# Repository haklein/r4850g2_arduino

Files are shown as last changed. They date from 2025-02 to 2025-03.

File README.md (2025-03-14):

# Huawai R4850G2 rectifier canbus control

  ## Based on:

   https://www.beyondlogic.org/review-huawei-r4850g2-power-supply-53-5vdc-3kw/
   https://github.com/craigpeacock/Huawei_R4850G2_CAN

  ## IMPORTANT

   - adjust CAN.setClockFrequency() to match the crystal on the MCP2515 Board
   - put a termination jumper on J1, didn't work without for me (AZDelivery MCP2515 board)
   - be careful with any Serial.print statements in the onReceive handler. This will lead to lost CAN frames.
   - no regular status request CAN frames are being sent while the menu is active, so the rectifier will
     fall back to offline values at some point (menu will hence timeout after 10s by default)

  ## Requirements 
   
   - this has been tested with an Arduino Mega 2560 and a Nano
   - libraries used:
      * Adafruit can library (forked from sandeepmistry/arduino-CAN):
        https://github.com/adafruit/arduino-CAN
      * ArduinoMenu (for Sketch `R4850G2_Menu.ino`, not required for `R4850G2_V2.ino`)
      * SSD1306Ascii (for Sketch `R4850G2_Menu.ino`, not required for `R4850G2_V2.ino`)
      * ClickEncoder (for Sketch `R4850G2_Menu.ino`, not required for `R4850G2_V2.ino`)

  ## Usage

Pressing the rotary button opens the menu. Voltage and current can be set with the rotary encoder. The "Apply" menu item sets the power supply to the chosen values. Using the "Persist" menu item (scroll down below "Apply") will permanently store the settings in the power supply. Those will then be the default startup values. The power supply will also fall back to those values when the CAN commuication is interrupted.
    
  ## PICTURES:









  ## PINOUT

  @Roturbo has provided a nice pinout for a nano: 

  316427349-3ad49603-3def-4ec2-9e40-f8289db90cfa

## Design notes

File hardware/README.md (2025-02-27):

# Hardware

This directory contains the schematics PDF and the Gerber zip.

PCB 2d view front
PCB 3d view front

The footprint for the SSD1306 has reversed SDA/SCL. The latest gerber fixes this (I2C pins cannot be changed on the pro mini).

## BOM

- Arduino Nano Pro
- EC11 rotary encoder (e.g. PEC11R-4215F-S0024)
- SSD1306 display
- MCP2515 CAN bus module (will be mounted flipped so boards with already soldered pins can be used)
- 2x 100nF 0805 for rotary debounce
- 2x 3,5mm screw terminal (optional, one can be salvaged from the CAN bus module)
- Female headers 2.54mm (optional when the break out boards are soldered directly to the PCB)

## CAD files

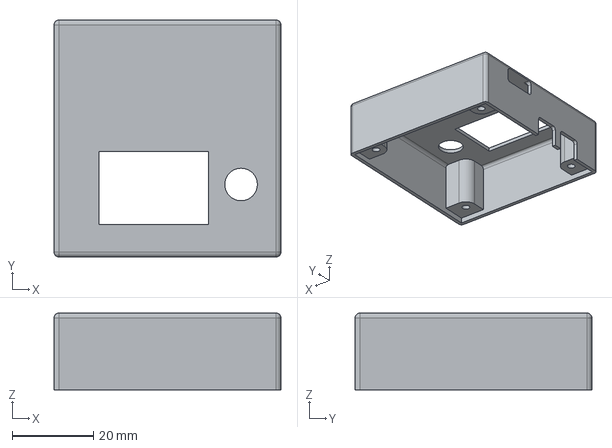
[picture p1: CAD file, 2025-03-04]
hardware/rg4850ctrl-BodyPocket001.step
55.8 x 58.2 x 18.9 mm

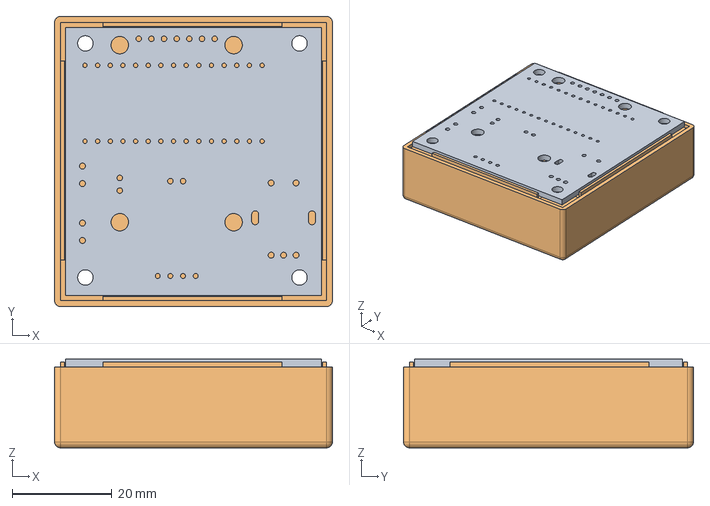
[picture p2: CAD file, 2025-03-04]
hardware/rg4850ctrl.FCStd
55.8 x 58.2 x 17.8 mm
BackupProjects_hari_1326_personal_0_20250303_PCB
Bottom

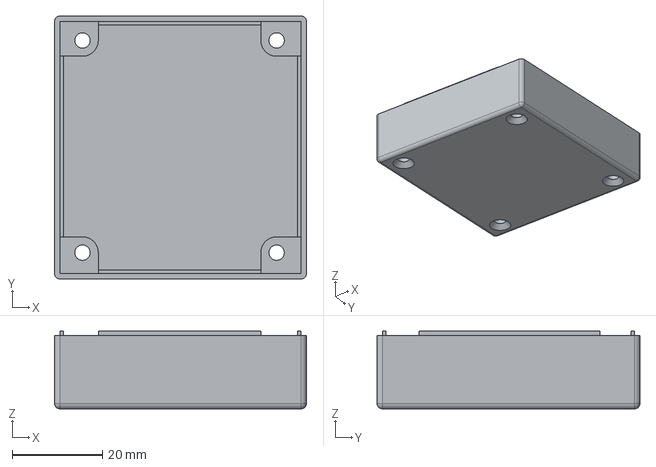
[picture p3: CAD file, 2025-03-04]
hardware/rg4850ctrl-BottomPad005.step
55.8 x 58.2 x 17.2 mm

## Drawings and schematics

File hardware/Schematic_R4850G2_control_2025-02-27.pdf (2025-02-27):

Arduino | CAN bus module | SSD 1306 Display

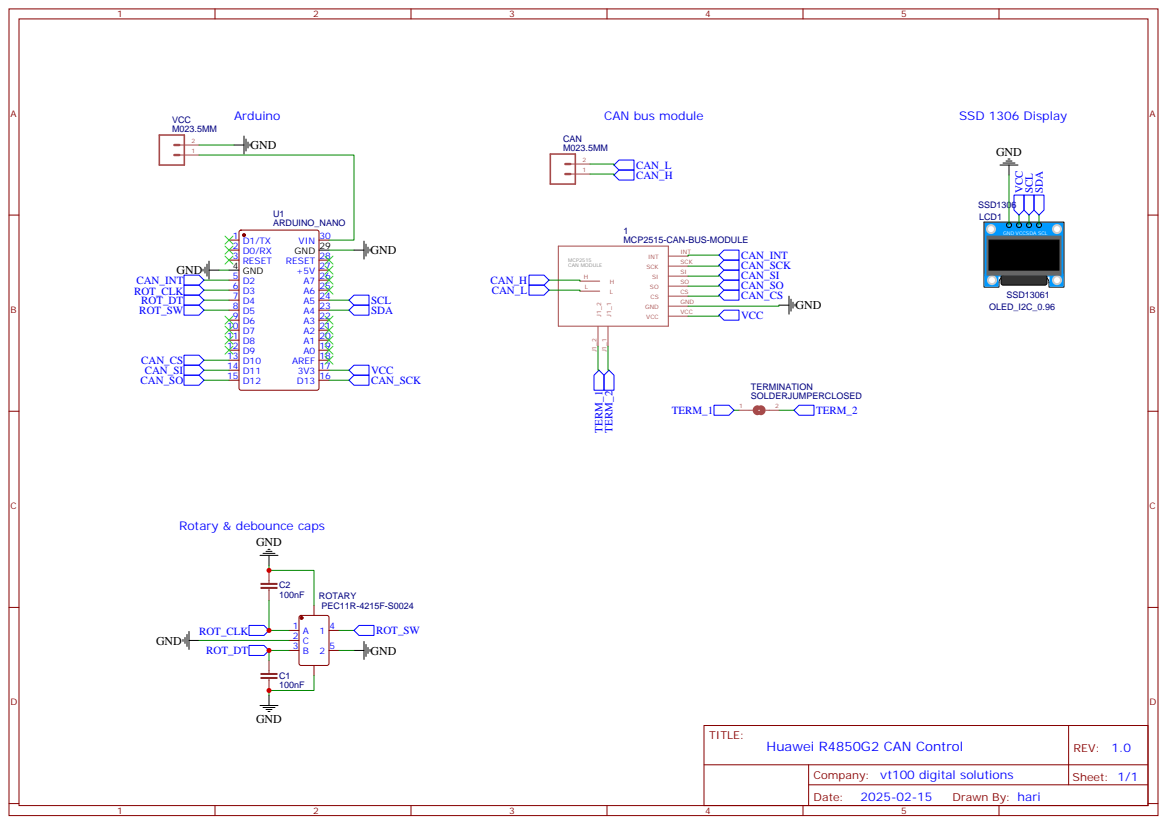
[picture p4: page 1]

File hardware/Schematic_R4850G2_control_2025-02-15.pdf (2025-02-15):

Arduino | CAN bus module | SSD 1306 Display

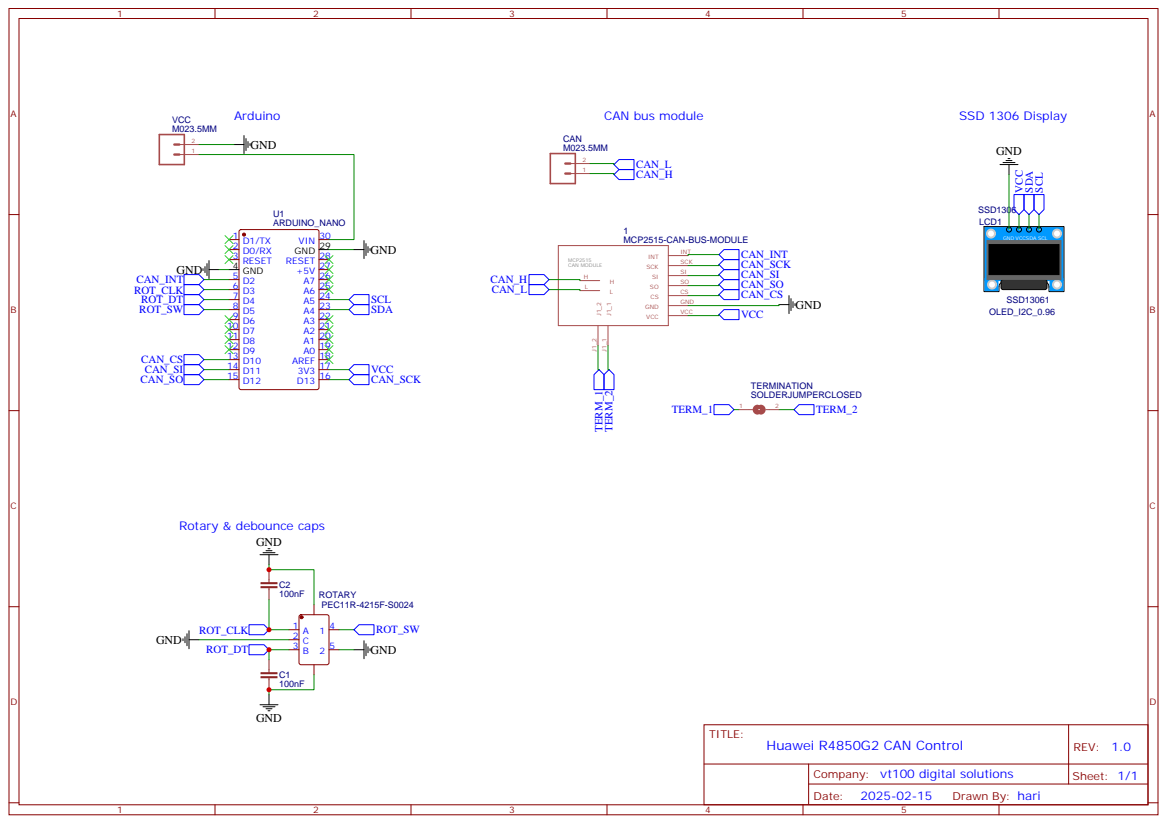
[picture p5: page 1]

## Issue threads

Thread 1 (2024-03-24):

Oled

Roturbo, 2024-03-24:
Hello,

i try to build this to adjust my r4850 power supply but no joy, display not working.

i have use 4 and 5 for oled SDA and SCL, i have 2 types of oled, the 0.96 and the 1.2" and they are working
because i try with other sketch.

Example, with sketch SH106-128-64_i2c, ssd1306_128x32_i2c, DisplayRotationWire,  Wire128x64SH1106 the oled works.

Can you please post the schematics for correct connection for oled and can-bus board,  also the type of Oled to use ?

Tanks in advance

.

haklein, 2024-03-24:
Hi, you do use the `R4850G2_Menu.ino` Sketch, right? Line 42 defines the i2c address of the Oled module. I'm using the 0.96" 1306 one. br Hari

Roturbo, 2024-03-25:
Hi,

the problem was the missing can module, the software hangs if there is no communication with the
can module and the display stays black,, i have look for the pin out and connect it, and it is working normal.

How about give the option to use the Oled 1.3" SH1106 ?

I leave here the connections,, if you want put it on first page to help others in future.

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

Regards

haklein, 2024-03-26:
Thanks a lot, I've added the pinout to the readme! I do not have a SH1106 to test, but feel free to submit a PR.

Roturbo, 2024-03-26:
Hi, ,

i will open a PR for the SH1106.

The picture is "private-user-images.",, i think you need to save it on you PC and upload it again for everyone to see it on the readme page.

regards.

haklein, 2024-03-26:
just did that, thanks!

Roturbo, 2024-03-28:
Hello,

Sorry i don´t have knowledge to make this type of changes and open a PR, my programming skills are very low.

The 1.3" oled is working, one or two vertical lines missing on the left but it is ok,  if you want and have the chance
to change the code i can try it and report here.

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

It´s working,, tank you for this.

Regards.

Closed 2024-05-19.

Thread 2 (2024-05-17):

menu version don't work per default

dl1bz, 2024-05-17:
The menu version don't work here , I found two problems:
1.
Reason: you forget to initialize the I2C bus:
add
```
Wire.begin();
Wire.setClock(400000L);
```
in the setup() function before you initialize the OLED, otherwise the 328 will be stopping/hang up.

2.
The second problem: runs not at an Arduino Nano per default.
Reason: compiled code to big for this CPU. You need to reduce code like some serial outputs. Use here the Arduino IDE 2.x with actual versions of all needed libs and using Ardunio Nano V3 from AZ Delivery and the 1,3" OLED display, which need a short patch too:
`oled.begin(&SH1106_128x64, SCREEN_ADDRESS);`

I2C address is in this case 0x3C (most 1.3" OLEDs are using 0x3D) for my display I use.

You can add a short scan routine for checking the I2C bus (helpful for find out the correct address for the used OLED):
```
//-----------------------------------------------------------------------------------------------------
// scan I2C bus for connected devices
void scanI2C() {
  byte error, address;
  int nDevices = 0;

  // Wire.begin();  // if not done before start I2C bus
  Serial.println(F("Scanning for I2C devices ..."));
  for(address = 0x01; address < 0x7f; address++){
    Wire.beginTransmission(address);
    error = Wire.endTransmission();
    if (error == 0){
      Serial.print(F("I2C device found at address 0x"));Serial.println(address,HEX);
      nDevices++;
    } else if(error != 2){
      Serial.print(F("Error "));Serial.print(error);Serial.print(F(" at address 0x"));Serial.println(address,HEX);
    }
  }
  if (nDevices == 0){
    Serial.println(F("No I2C devices found"));
  }
  delay(3000);
}
//-----------------------------------------------------------------------------------------------------
```

After this fixes your program works :)

haklein, 2024-05-19:
Looking at the examples from the SSD1306Ascii library this didn't seem to be mandatory. Also it did work for me on two different boards (nano and mega2560) and also for other users. Still good to know that this might be required in some situations, so thanks a lot for your comment! I didn't use the Version 2 IDE a lot as I do find PIO & vscode much more convenient. 73

Closed 2024-05-19.

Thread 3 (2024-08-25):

menu.h error

buddhafragt, 2024-08-25:
Hello, while compiling I always get a error:
.....R4850G2_Menu.ino:130:1: error: 'result' does not name a type
 result persist(eventMask e) {

Do you have a idea, whats wrong? I try different Arduino IDE versions and Arduinomenu versions, but still the same.

buddhafragt, 2024-08-29:
can not find the reason....
maybe the clickencoder library is wrong, which one you use?

haklein, 2024-09-02:
> can not find the reason.... maybe the clickencoder library is wrong, which one you use?

I think the one from 0xpit, need to check. You could try his `platformio.ini` (move the ino sketch to a directory named `src`):
```
[platformio]

[env:nanoatmega328]
platform = atmelavr
board = nanoatmega328

framework=arduino
lib_deps=
	neu-rah/ArduinoMenu library@^4.21.4
	greiman/SSD1306Ascii@^1.3.5
	0xpit/ClickEncoder
	sandeepmistry/CAN@^0.3.1
	paulstoffregen/TimerOne@^1.1.1
```

buddhafragt, 2024-09-05:
Thanks, I was trying to compile with the ArduinoIDE, this is not working.
With PlatformIO the code compiles.
Suggestion:
With my board I need to change in the .ini file the board to:
board = nanoatmega328new

Closed 2024-09-05.

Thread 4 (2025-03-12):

Request: Set default power voltage

myhobby2, 2025-03-12:
Removed initial request because with scanning the written Arduino code (I can't program), I saw that it should be possible to set the default start values.

Can you provide a short manual how to use the controller to set/change values so it is clear to me. Currently working based on assumptions ;-)

haklein, 2025-03-13:
Hello @myhobby2

you can "persist" the setting via the menu. This is the action right below the "apply". Persisted values will be the default start ones, and the power supply also reverts to them when the CAN communication is lost.

br Hari

myhobby2, 2025-03-14:
Thanks for your confirmation. Initially I did not see this option in the menu for whatever reason. I think you created a wonderful solution. As a new user to your work, I'm working with a lot of assumptions in the menu and that is why I asked for a few words on using the menu and dail/push button.. (I think it is still the icing on the cake ;-) )

haklein, 2025-03-14:
I've added usage notes to the readme.

Closed 2025-03-14.

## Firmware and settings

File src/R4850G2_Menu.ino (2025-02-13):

/*
   Huawai R4850G2 rectifier canbus control


   Based on:

   https://www.beyondlogic.org/review-huawei-r4850g2-power-supply-53-5vdc-3kw/
   https://github.com/craigpeacock/Huawei_R4850G2_CAN

   Improvements from dl1bz

   IMPORTANT:

   - adjust CAN.setClockFrequency() to match the crystal on the MCP2515 Board
   - put a termination jumper on J1, didn't work without for me
   - be careful with any Serial.print in the onReceive handler. This will lead to lost CAN frames.
   - this has been tested with an Arduino Mega 2560 and Nano
   - libraries used:
        Adafruit can library (forked from sandeepmistry/arduino-CAN):
        https://github.com/adafruit/arduino-CAN
        ArduinoMenu
        SSD1306Ascii
        ClickEncoder

   Mega 2560 SPI pins:

   2 - int
   10 - CS
   50 - SO
   51 - SI
   52 - SCK
*/

#define menuFont X11fixed7x14
#define fontW 7  // 7
#define fontH 15   // 15

#define statusFont Adafruit5x7

#define SCREEN_WIDTH 128 // OLED display width, in pixels
#define SCREEN_HEIGHT 64 // OLED display height, in pixels

#define OLED_RESET     4 // Reset pin # (or -1 if sharing Arduino reset pin)
#define SCREEN_ADDRESS 0x3c ///< See datasheet for Address; 0x3D for 128x64, 0x3C for 128x32

#define ROTARY_PIN_CLK 3
#define ROTARY_PIN_DT 4
#define ROTARY_PIN_SW 5

#define VOLT_LIMIT_LOW 41.5
#define VOLT_LIMIT_HIGH 58.5
#define AMP_LIMIT_LOW 0.0
#define AMP_LIMIT_HIGH 60.0

#define VOLT_DEFAULT 55.2 
#define AMP_DEFAULT 1.0

#define MENU_TIMEOUT 10  // sketch doesn't send CAN frames while in menu, so timeout early to prevent
                         // rectifier from defaulting to offline values
                         
#define MAX_DEPTH 1 // menu depth

#include <CAN.h>

#include <SPI.h>
#include <Wire.h>

#include <SSD1306Ascii.h>
#include <SSD1306AsciiWire.h>

#include <TimerOne.h>

#include <ClickEncoder.h>

#include <menu.h>
#include <menuIO/SSD1306AsciiOut.h>
#include <menuIO/clickEncoderIn.h>
#include <menuIO/keyIn.h>
#include <menuIO/chainStream.h>

#define DEBUG 1

#define MAX_CURRENT_MULTIPLIER    20

#define R48xx_DATA_INPUT_POWER    0x70
#define R48xx_DATA_INPUT_FREQ   0x71
#define R48xx_DATA_INPUT_CURRENT  0x72
#define R48xx_DATA_OUTPUT_POWER   0x73
#define R48xx_DATA_EFFICIENCY   0x74
#define R48xx_DATA_OUTPUT_VOLTAGE 0x75
#define R48xx_DATA_OUTPUT_CURRENT_MAX 0x76
#define R48xx_DATA_INPUT_VOLTAGE  0x78
#define R48xx_DATA_OUTPUT_TEMPERATURE 0x7F
#define R48xx_DATA_INPUT_TEMPERATURE  0x80
#define R48xx_DATA_OUTPUT_CURRENT 0x81
#define R48xx_DATA_OUTPUT_CURRENT1  0x82

struct RectifierParameters
{
  float input_voltage;
  float input_frequency;
  float input_current;
  float input_power;
  float input_temp;
  float efficiency;
  float output_voltage;
  float output_current;
  float max_output_current;
  float output_power;
  float output_temp;
  float amp_hour;
};

using namespace Menu;

SSD1306AsciiWire oled;

ClickEncoder clickEncoder(ROTARY_PIN_CLK, ROTARY_PIN_DT, ROTARY_PIN_SW, 4); // last parameter: steps per notch
ClickEncoderStream encStream(clickEncoder, 1);

struct RectifierParameters rp;

unsigned long g_Time1000 = 0;

bool doPrint = false;

float volts = VOLT_DEFAULT;
float amps = AMP_DEFAULT;

result persist(eventMask e) {
  Serial.println(F("persist executed")); Serial.flush();
  Serial.println(volts);
  Serial.println(amps);
  r4850_set_voltage(volts, true);
  delay(250);
  r4850_set_current(amps, true);
  delay(250);
  return proceed;
}

result apply(eventMask e) {
  Serial.println(F("apply executed")); Serial.flush();
  Serial.println(volts);
  Serial.println(amps);
  r4850_set_voltage(volts, false);
  delay(250);
  r4850_set_current(amps, false);
  delay(250);
  return quit;
}

result doAlert(eventMask e, prompt &item);

MENU_INPUTS(in, &encStream);

MENU(mainMenu, "R4850 Settings", Menu::doNothing, Menu::noEvent, Menu::wrapStyle
     , FIELD(volts, "Volts", "V", VOLT_LIMIT_LOW, VOLT_LIMIT_HIGH, 1, 0.1, doNothing, noEvent, wrapStyle)
     , FIELD(amps, "Amps", "A", AMP_LIMIT_LOW, AMP_LIMIT_HIGH, 1, 0.1, doNothing, noEvent, wrapStyle)
     , OP(">Apply", apply, enterEvent)
     , OP(">Persist", persist, enterEvent)
     , EXIT("<Back")
    );

const panel panels[] MEMMODE = {{0, 0, 128 / fontW, 64 / fontH}};
navNode* nodes[sizeof(panels) / sizeof(panel)]; //navNodes to store navigation status
panelsList pList(panels, nodes, 1); //a list of panels and nodes
idx_t tops[MAX_DEPTH] = {0}; //store cursor positions for each level
SSD1306AsciiOut outOLED(&oled, tops, pList, 8, 1+((fontH - 1) >> 3) ); //oled output device menu driver
menuOut* constMEM outputs[] MEMMODE = {&outOLED}; //list of output devices
outputsList out(outputs, 1); //outputs list

NAVROOT(nav, mainMenu, MAX_DEPTH, in, out);

int r4850_ack(uint8_t *frame)
{
  bool error = frame[0] & 0x20;
  uint32_t value = __builtin_bswap32(*(uint32_t *)&frame[4]);

  switch (frame[1]) {
    case 0x00:
      Serial.print(F("Setting on-line voltage: "));
      break;
    case 0x01:
      Serial.print(F("Setting off-line voltage: "));
      break;
    case 0x02:
      Serial.print(F("Setting OVP: "));
      break;
    case 0x03:
      Serial.print(F("Setting on-line current: "));
      break;
    case 0x04:
      Serial.print(F("Setting off-line current: "));
      break;
    default:
      Serial.print(F("Setting unknown parameter: "));
      break;
  }
  Serial.println(error ? F("ERROR") : F("SUCCESS"));
}

int r4850_data(uint8_t *frame, struct RectifierParameters *rp)
{
  uint32_t value = __builtin_bswap32(*(uint32_t *)&frame[4]);

  switch (frame[1]) {
    case R48xx_DATA_INPUT_POWER:
      rp->input_power = value / 1024.0;
      break;

    case R48xx_DATA_INPUT_FREQ:
      rp->input_frequency = value / 1024.0;
      break;

    case R48xx_DATA_INPUT_CURRENT:
      rp->input_current = value / 1024.0;
      break;

    case R48xx_DATA_OUTPUT_POWER:
      rp->output_power = value / 1024.0;
      break;

    case R48xx_DATA_EFFICIENCY:
      rp->efficiency = value / 1024.0;
      break;

    case R48xx_DATA_OUTPUT_VOLTAGE:
      rp->output_voltage = value / 1024.0;
      break;

    case R48xx_DATA_OUTPUT_CURRENT_MAX:
      rp->max_output_current = value / MAX_CURRENT_MULTIPLIER;
      break;

    case R48xx_DATA_INPUT_VOLTAGE:
      rp->input_voltage = value / 1024.0;
      break;

    case R48xx_DATA_OUTPUT_TEMPERATURE:
      rp->output_temp = value / 1024.0;
      break;

    case R48xx_DATA_INPUT_TEMPERATURE:
      rp->input_temp = value / 1024.0;
      break;

    case R48xx_DATA_OUTPUT_CURRENT1:
      // Serial.println("R48xx_DATA_OUTPUT_CURRENT1");
      //printf("Output Current(1) %.02fA\r\n", value / 1024.0);
      //rp->output_current = value / 1024.0;
      break;

    case R48xx_DATA_OUTPUT_CURRENT:
      rp->output_current = value / 1024.0;

      /* This is normally the last parameter received. Print */
      doPrint = true;
      break;

    default:
      //printf("Unknown parameter 0x%02X, 0x%04X\r\n",frame[1], value);
      break;

  }
}


void onCANReceive(int packetSize)
{
  if (!CAN.packetExtended())
    return;
  if (CAN.packetRtr())
    return;

  uint32_t msgid = CAN.packetId();
  uint8_t data[packetSize];

  CAN.readBytes(data, sizeof(data));

  switch (msgid & 0x1FFFFFFF) {

    case 0x1081407F:
      // Serial.print("Data frame: ");
      r4850_data((uint8_t *)&data, &rp);
      // Serial.println();
      break;
    case 0x1081407E:
      /* Acknowledgment */
      // Serial.println("Ack frame");
      break;
    case 0x1081D27F:
      // Serial.println("Description");
      // r4850_description((uint8_t *)&frame.data);
      break;
    case 0x1081807E:
      // Serial.println("Ack frame");
      r4850_ack((uint8_t *)&data);
      break;
    case 0x1001117E:
      // Serial.println("Amp hour frame");
      break;
    case 0x100011FE:
      // Serial.println("Normally  00 02 00 00 00 00 00 00 ");
      break;
    case 0x108111FE:
      // Serial.println("Normally 00 03 00 00 00 0s 00 00, s=1 when output enabled ");
      break;
    case 0x108081FE:
      // Serial.println("Normally 01 13 00 01 00 00 00 00 ");
      break;

    default:
      Serial.println(F("ERROR: Unknown Frame!"));
      break;
  }
}

int r4850_request_data()
{
  uint8_t data[8];
  data[0] = 0x00;
  data[1] = 0x00;
  data[2] = 0x00;
  data[3] = 0x00;
  data[4] = 0x00;
  data[5] = 0x00;
  data[6] = 0x00;
  data[7] = 0x00;

  return sendCAN( 0x108040FE , data, 8, true);
}

int r4850_set_voltage(float voltage, bool nonvolatile)
{
  uint16_t value = voltage * 1024;
  //printf("Voltage = 0x%04X\n",value);

  uint8_t command;

  if (nonvolatile) command = 0x01;  // Off-line mode
  else     command = 0x00;  // On-line mode

  uint8_t data[8];
  data[0] = 0x01;
  data[1] = command;
  data[2] = 0x00;
  data[3] = 0x00;
  data[4] = 0x00;
  data[5] = 0x00;
  data[6] = (value & 0xFF00) >> 8;
  data[7] = value & 0xFF;

  return sendCAN( 0x108180FE , data, 8, false);
}

int r4850_set_current(float current, bool nonvolatile)
{
  uint16_t value = current * MAX_CURRENT_MULTIPLIER;
  uint8_t command;

  if (nonvolatile) command = 0x04;  // Off-line mode
  else     command = 0x03;  // On-line mode

  uint8_t data[8];
  data[0] = 0x01;
  data[1] = command;
  data[2] = 0x00;
  data[3] = 0x00;
  data[4] = 0x00;
  data[5] = 0x00;
  data[6] = (value & 0xFF00) >> 8;
  data[7] = value & 0xFF;

  return sendCAN( 0x108180FE , data, 8, false);

}
int sendCAN(uint32_t msgid, uint8_t *data, uint8_t len, bool rtr)
{
  CAN.beginExtendedPacket(msgid, len, rtr);

  CAN.write(data, len);
  if (!CAN.endPacket()) {
    Serial.println(F("ERROR: Couldn't send CAN packet"));
    oled.setFont(statusFont);
    oled.clear();
    oled.set2X();
    oled.println("CAN err");
    oled.set1X();
    oled.println(millis());
    oled.setFont(menuFont);
    return -1;
  }
  return 0;
}
void timerIsr() {
  clickEncoder.service();
}
void setup() {
  Serial.begin(115200);
  while (!Serial)
    ;
  Serial.println(F("INFO: Booting up..."));

  pinMode(ROTARY_PIN_SW, INPUT_PULLUP);
  Timer1.initialize(1000);
  Timer1.attachInterrupt(timerIsr); // used for rotary decoder

  CAN.setClockFrequency(8E6); // 8 MHz for Adafruit MCP2515 CAN Module

  if (!CAN.begin(125E3)) // 125kbit
  {
    Serial.println(F("ERROR: Starting CAN failed! Aborting."));
    while (1)
      ;
  }
  CAN.onReceive(onCANReceive);

  Serial.println(F("INFO: CAN setup done."));

  Wire.begin();
  // Wire.setClock(400000L); # might be required on some boards
  oled.begin(&Adafruit128x64, SCREEN_ADDRESS);
  //  oled.begin(&SH1106_128x64, SCREEN_ADDRESS); # use this instead on AZDelivery v3 nano board due to space constraints
  oled.setFont(menuFont);
  oled.clear();
  oled.println(F("R4850G2 Inverter"));
  oled.println("Starting..");

  delay(500);
  nav.timeOut = MENU_TIMEOUT;
  nav.idleOn();
}

void loop() {
  nav.poll();
  if (nav.sleepTask) { // menu is idle, do our business

    if ((millis() - g_Time1000) > 1000)
    {
      g_Time1000 = millis();
      Serial.println(F("req data..."));
      r4850_request_data();
    }
    if (doPrint) {
      doPrint = false;

      delay(10);
      oled.setFont(statusFont);

      oled.home();
      oled.print(F("I:"));
      oled.print(int(rp.input_voltage));
      oled.print(F("V;"));
      oled.print(int(rp.input_current));
      oled.print(F("A;"));
      oled.print(int(rp.input_power));
      oled.print(F("W"));
      oled.println(F("     "));
      oled.print(F("T:"));
      oled.print(int(rp.input_temp));
      oled.print(F("C;"));
      oled.print(int(rp.output_temp));
      oled.print(F("C;"));
      oled.print(int(rp.input_frequency));
      oled.print(F("Hz"));
      oled.println(F("     "));
      oled.set2X();
      oled.print(rp.output_voltage);
      oled.println(F("V     "));
      oled.print(rp.output_current);
      oled.println(F("A           "));
      oled.set1X();
      oled.print(F("/"));
      oled.print(rp.max_output_current);
      oled.println(F("A;"));
      oled.print(rp.output_power);
      oled.print(F("W           "));
      oled.setFont(menuFont);

      Serial.println(F("RECV:"));
      Serial.print(F("INPUT_POWER: "));
      Serial.println(rp.input_power);
      Serial.print(F("INPUT_FREQ: "));
      Serial.println(rp.input_frequency);
      Serial.print(F("INPUT_CURRENT: "));
      Serial.println(rp.input_current);
      Serial.print(F("OUTPUT_POWER: "));
      Serial.println(rp.output_power);
      Serial.print(F("EFFICIENCY: "));
      Serial.println(rp.efficiency);
      Serial.print(F("OUTPUT_VOLTAGE: "));
      Serial.println(rp.output_voltage);
      Serial.print(F("OUTPUT_CURRENT_MAX: "));
      Serial.println(rp.max_output_current);
      Serial.print(F("INPUT_VOLTAGE: "));
      Serial.println(rp.input_voltage);
      Serial.print(F("OUTPUT_TEMPERATURE: "));
      Serial.println(rp.output_temp);
      Serial.print(F("INPUT_TEMPERATURE: "));
      Serial.println(rp.input_temp);
      Serial.println("OUTPUT_CURRENT1");
      Serial.print(F("OUTPUT_CURRENT: "));
      Serial.println(rp.output_current);

    }
  }
}

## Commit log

2023-08-28 version with ArduinoMenu for SSD1306 OLED and rotary encoder
2024-05-19 fixes #2 - improvements from dl1bz
    [R4850G2_Menu.ino]
2025-03-04 3d files for printed enclosure
    [rg4850ctrl-BodyPocket001.step, rg4850ctrl-BottomPad005.step, rg4850ctrl.FCStd]
2025-03-04 add image from enclosure
2025-03-04 add PCB image
